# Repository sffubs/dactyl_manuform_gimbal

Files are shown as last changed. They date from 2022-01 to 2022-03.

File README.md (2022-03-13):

# Dactyl-Manuform-Gimbal keyboard
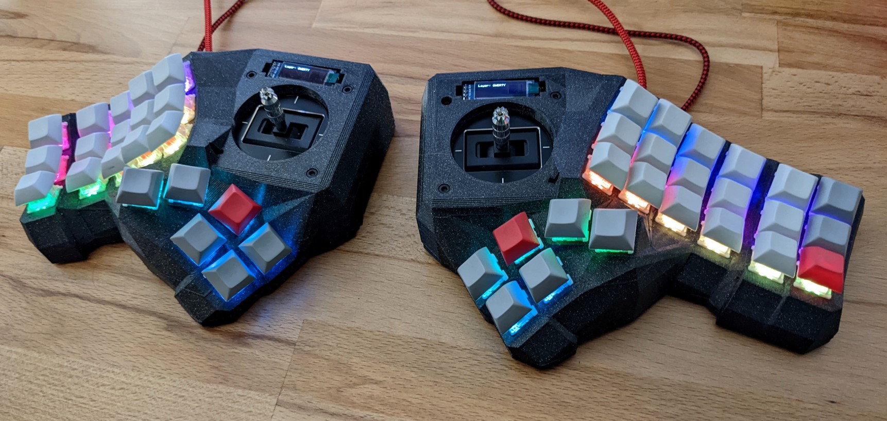
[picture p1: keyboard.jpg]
keyboard


Why? I wanted to build something a bit different, something that I'd not seen before. I wondered what a keyboard would look like if I merged it with an RC controller, and tried using the RC gimbals as a mouse.

The result is quite fun. It's fairly space-efficient, and allows me to use the mouse with either hand. It has proximity sensors to detect when your hand is on the joystick, and turns some of the keys into mouse buttons. Haptic feedback helps to tell when you have switched layers, or long-pressed a key.

You might have noticed it has more keys on the right than the left. This is because I wanted the option to use it with [Plover](http://www.openstenoproject.org/plover/), which for a standard layout requires a minimum of 6 columns on the right, and 5 columns on the left. (I've not actually tested it with Plover, having built a [different keyboard](https://www.thingiverse.com/thing:5021950) for that in the meantime).

Fair warning: there is quite a lot of soldering involved if you want to make one:

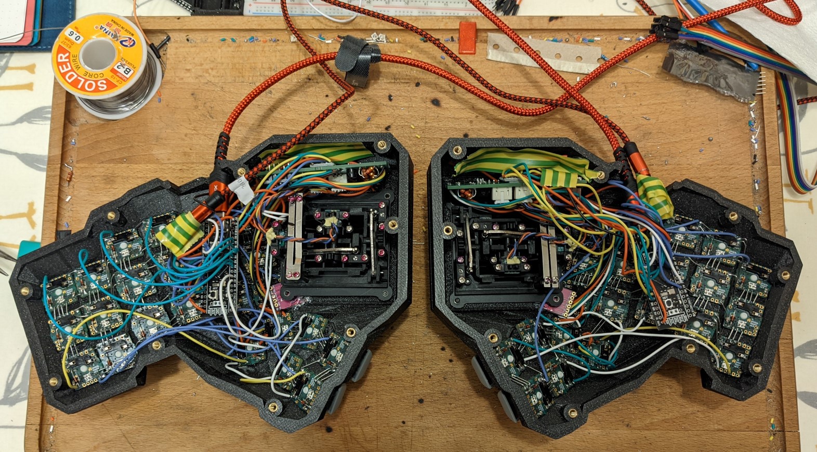
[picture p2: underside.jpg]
underside


## Components
### Keys
I picked gateron red switches and DSA keycaps, sold to me by [Mechboards](mechboards.co.uk).

### Gimbals
The twist in this design is the inclusion of a pair of joysticks. These are RC gimbals - see [here](FrSky_M9.md) for some details of how they are wired up.

### Proximity
The keyboard uses a proximity switch to detect when a hand is over the joystick, and uses this to switch the mouse buttons on. This is using an [APDS-9660](https://www.sparkfun.com/products/12787) sensor & breakout board which is glued to the underside of the case (it's the purple circuit board visible under the corner of the gimbal).

Here it is working:



The proximity sensor looks up through the little square hole next to the gimbal, so your hand needs to be somewhere over that hole for it to activate:

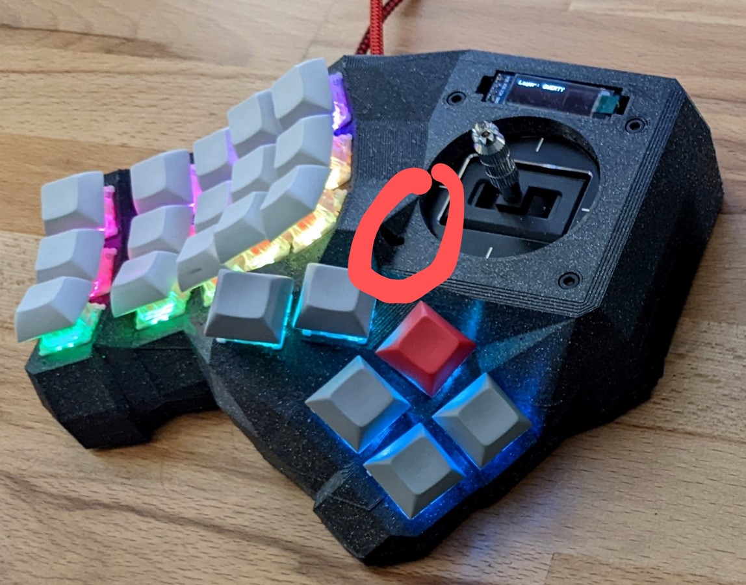
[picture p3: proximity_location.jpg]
proximity location


It will trigger unexpectedly if you get hair over that hole, so I advise you to keep your cat away from it.

### Controller
Originally this was designed to work with two [Pro Micro](https://www.sparkfun.com/products/12640) controllers, but these didn't really have enough flash for the QMK features I wanted.

So I used a beefier board that I was familiar with: the [Teensy 3.2](https://www.hobbytronics.co.uk/teensy-v32), which has been really good to me before. However, it turns out that QMK only sort-of supports the Teensy, so I had a lot of trouble getting it to work reliably.

In the end, I gave up, and swapped to a pair of [STM32F401CCU6 "Black pill"](https://stm32-base.org/boards/STM32F401CCU6-WeAct-Black-Pill-V1.2.html) controllers. These work flawlessly with QMK, though I did manage to kill two boards during assembly, and I'm not quite sure how.

In any case, the swap from the original 5v board to a 3.3v one meant that a level-shifter had to be added between the board and the I2C and LED lines on the breakout board.

Here's how the blackpill controller is wired:

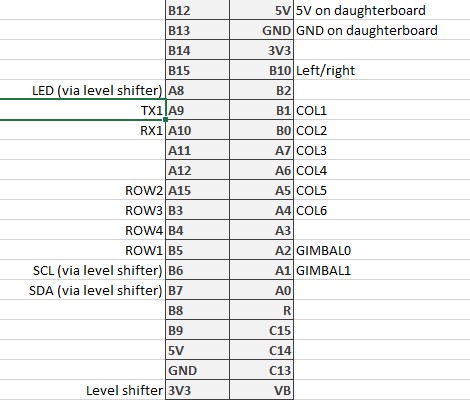
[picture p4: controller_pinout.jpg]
controller_pinout


B10 should be wired to 3V3 on the left-hand half, and to GND on the right-hand half.

Remember that TX1 on the left-hand half needs to be connected to RX1 on the right-hand half, and vice-versa.

### Haptic
I wanted to try getting some haptic feedback from the keyboard, for example when using mod-taps, or when switching to/from mouse mode. QMK has support for the [DRV2605L](https://learn.adafruit.com/adafruit-drv2605-haptic-controller-breakout) driver built in, so I used this.

I picked a linear resonant actuator to use with it, the Jinlong G0832012. Not for any highly specific reason; it was easily available and looked like roughly the right thing.

### LEDs & per-key PCBs
Per-key RGB LEDs are the cornerstone of a fancy mechanical keyboard! I had to have them. To try and keep things tidy, I used [Amoeba Royale](https://github.com/mtl/keyboard-pcbs/tree/master/amoeba-royale) per-key PCBs, printed for me by [Aisler](https://aisler.net). I got a bunch of SK6812 mini 3535 LEDs to to go with them, along with kailh hotswap sockets, and some small signal diodes.

Honestly, they were still quite painful to use. The holes in the PCB had to be filed out before the LEDs would fit in them, and the LED casings would melt if the soldering iron was on them for more than half a second. I had a couple of PCBs that were faulty also.

Here was my method for soldering them:
- Sit the LED in the hole
- Spread some flux over the back of the LED
- For each terminal
	- Put some solder on the PCB pad
	- Dag it onto the LED. Hopefully you will get a little solder bridge form
- Try once for each pad, and if it didn't work, leave it for a couple of minutes to cool before you try again.
- Repeat until all connections are made, then test the PCB.

However, once the whole lot was wired up, they do look quite tidy. The PCBs are not secured to the case, it seems to be enough just to press-fit them onto the back of the keys.

### Split communication
The two halves communicate through a TRRS connector. However, this just provides serial communications and a common ground wire - I left the 5v wire unconnected. Both of the halves need to be connected to the host computer over USB. This is for two reasons:
- Each half can send its own mouse events, which simplifies things
- I think the power draw for the whole keyboard might exceed 500ma - certainly I had some problems trying to power the whole thing from a single USB port

### OLED
I bought a pair of "OLED screens" from Mechboards, because of course I wanted my keyboard to have a screen! Actually this turned out to be a really helpful debugging tool, and I ended up printing a lot of diagnostic information to the OLED screen. I suspect they are SSD1306 128x32 screens, since they worked in QMK without any modifications.

## Daughterboard PCB
There are a lot of connections in this keyboard: the haptic breakout board, proximity board, OLED, LED, gimbals, TRRS connection. Wiring all of these directly to the controller would be difficult.

To simplify things, I designed a PCB to hold all of these connections. It also contains a 3.3v regulator to drive the ADPS9660 board, from back when the whole system was designed to run on 5v.
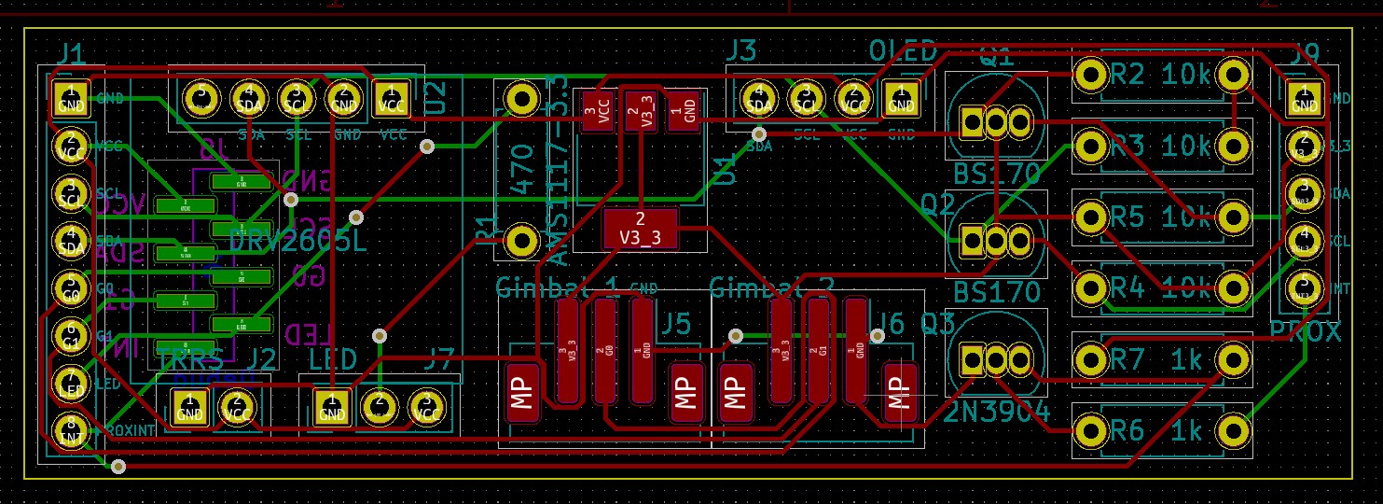
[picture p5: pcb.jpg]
PCB


Originally the SCL, SDA, and LED connections on the left were meant to go straight to pins on the pro micro controller. However, when using this with a blackpil controller, you will need to use a [level shifter](https://learn.sparkfun.com/tutorials/bi-directional-logic-level-converter-hookup-guide/all) to convert between 3.3v and 5v.

Here are the sources:
- [dactyl-manuform-gimbal.kicad_pcb](dactyl-manuform-gimbal.kicad_pcb)
- [dactyl-manuform-gimbal.pro](dactyl-manuform-gimbal.pro)
- [dactyl-manuform-gimbal.sch](dactyl-manuform-gimbal.sch)

I had mine manufactured by [Aisler](https://aisler.net/).

You will also need these parts to make up the board:
- Q3: 2N3904 TO-92
- R6 & R7: 1k resistor
- R2, R3, R4, R5: 10k resistor
- Q1 & Q2: BS170 TO-92
- R1: 470R resistor
- J5 & J6: JST_PH_B3B header
- AMS1117 3.3v voltage regulator
- Adafruit DRV2506L haptic driver

## Geometry
The geometry was generated using a fork of Joshua Shreve's dactyl-keyboard generator:

https://github.com/sffubs/dactyl-keyboard/tree/gimbal

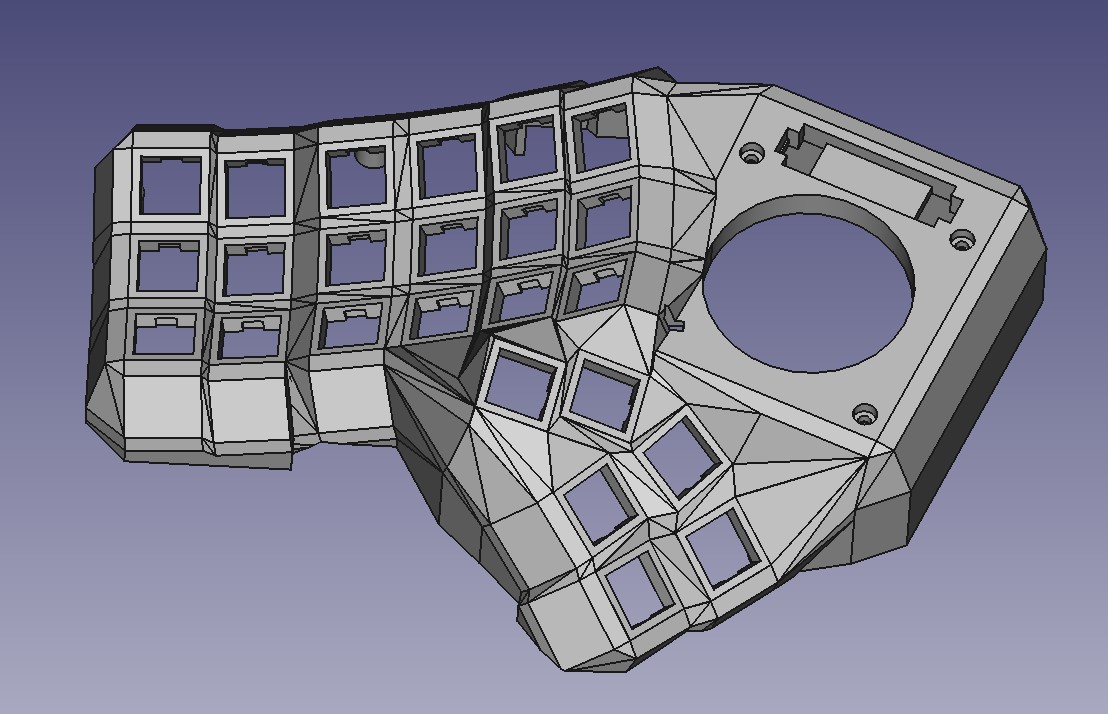
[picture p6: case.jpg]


I custom-designed some controller trays to fit:

https://cad.onshape.com/documents/eb5f1e8bc035539a3b22c66d/w/b0de5830ef436e9c93686258/e/9e4ae3f698d1b142e7089f96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

This for the right-hand keyboard - you will need to print the mirror image for the left-hand keyboard.

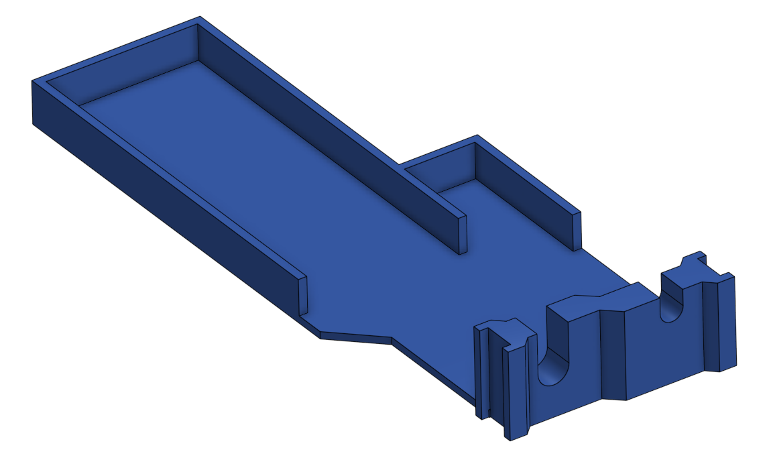
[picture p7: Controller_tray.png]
Controller tray


The final files I used are here:
- [DM_left_final.step](DM_left_final.step)
- [DM_left_final.stl](DM_left_final.stl)
- [DM_left_plate_final.stp](DM_left_plate_final.stp)
- [DM_left_plate_final.stl](DM_left_plate_final.stl)
- [DM_right_final.step](DM_right_final.step)
- [DM_right_final.stl](DM_right_final.stl])
- [DM_right_plate_final.step](DM_right_plate_final.step)
- [DM_right_plate_final.stl](DM_right_plate_final.stl)
- [Controller_tray.stl](Controller_tray.stl)
- [DM_OLED_clip.stl](DM_OLED_clip.stl)

## Printing
I printed this on my Ender 3, using Prusament Galaxy Black PLA filament, with a 0.4mm nozzle at 0.2mm resolution. I used tree-style supports, which much reduced the time and plastic required.

## Firmware

The keyboard runs on QMK, and the firmware can be found here:

https://github.com/sffubs/qmk_firmware/tree/master/keyboards/handwired/dactyl_manuform_gimbal

Build using 

`qmk -kb handwired/dactyl_manuform_gimbal -km default`

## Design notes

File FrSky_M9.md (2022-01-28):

# Frsky M9 gimbal

## Wiring

These are 3.3v hall-effect joysticks. They have two sensors which are wired as:
- Red: 3.3v
- Black: 0v
- Yellow or blue: signal (between 0v and 3.3v)

These signals can be easily read using an ADC, and used to make a USB joystick or mouse.

Here's the joystick as it arrives:

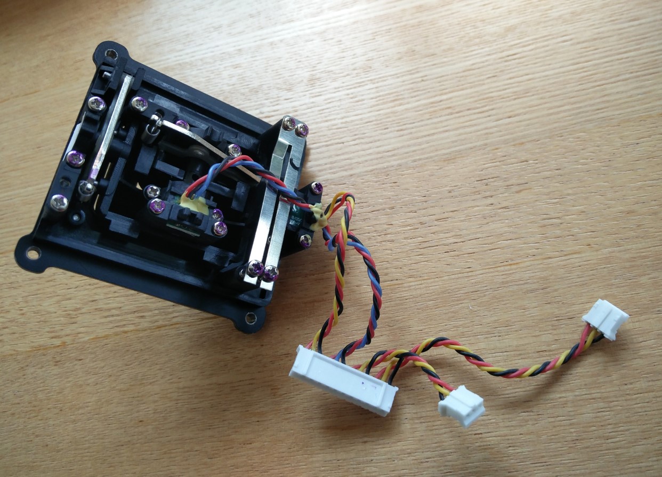
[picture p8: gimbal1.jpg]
gimbal1


The wires are all connected to this large JST connector, for installation into a Taranis RC controller:

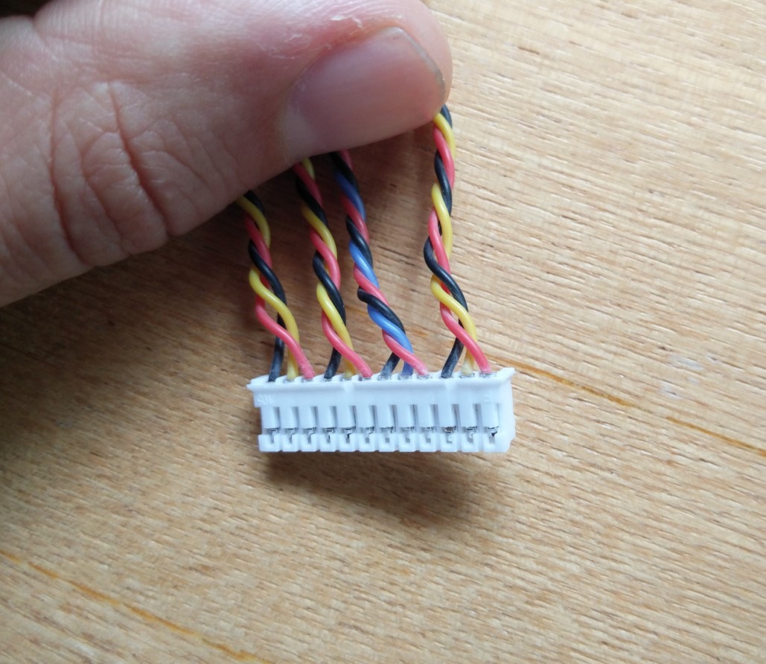
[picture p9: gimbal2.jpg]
gimbal2

Using a craft knife, you can lift the plastic tabs of the JST connectors, and pull the pins out. Then you can just plug the critical wires back into the 3-pin JST connectors:

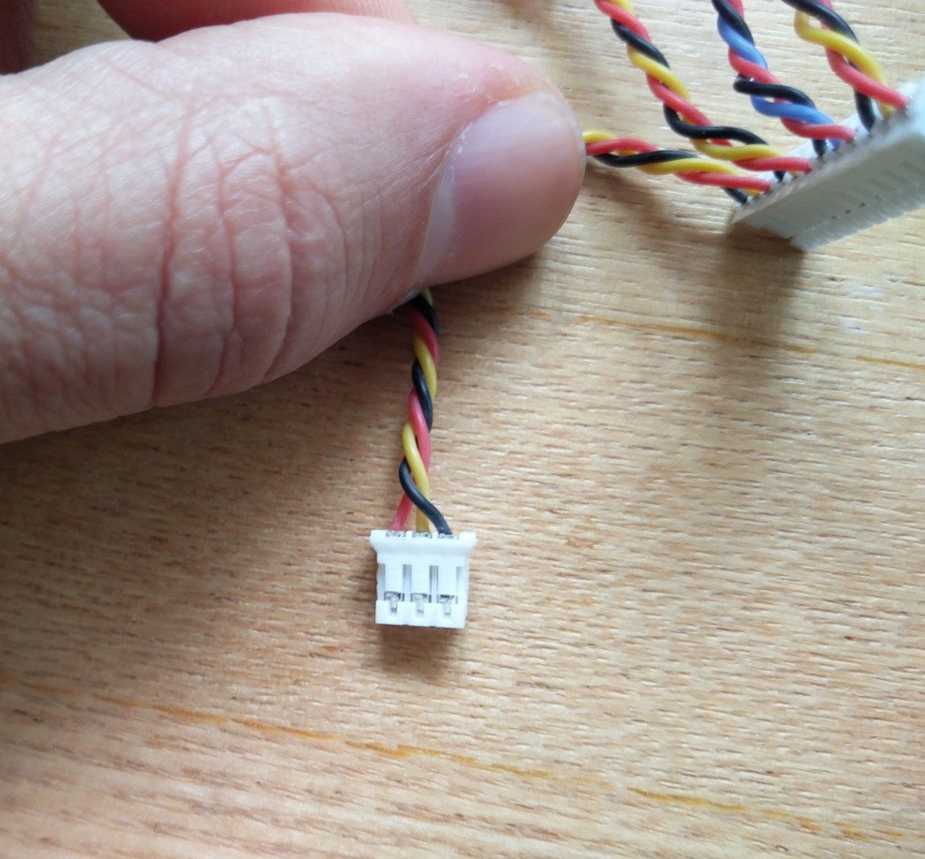
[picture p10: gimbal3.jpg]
gimbal3

The end result is much more suitable for integrating into a different project:

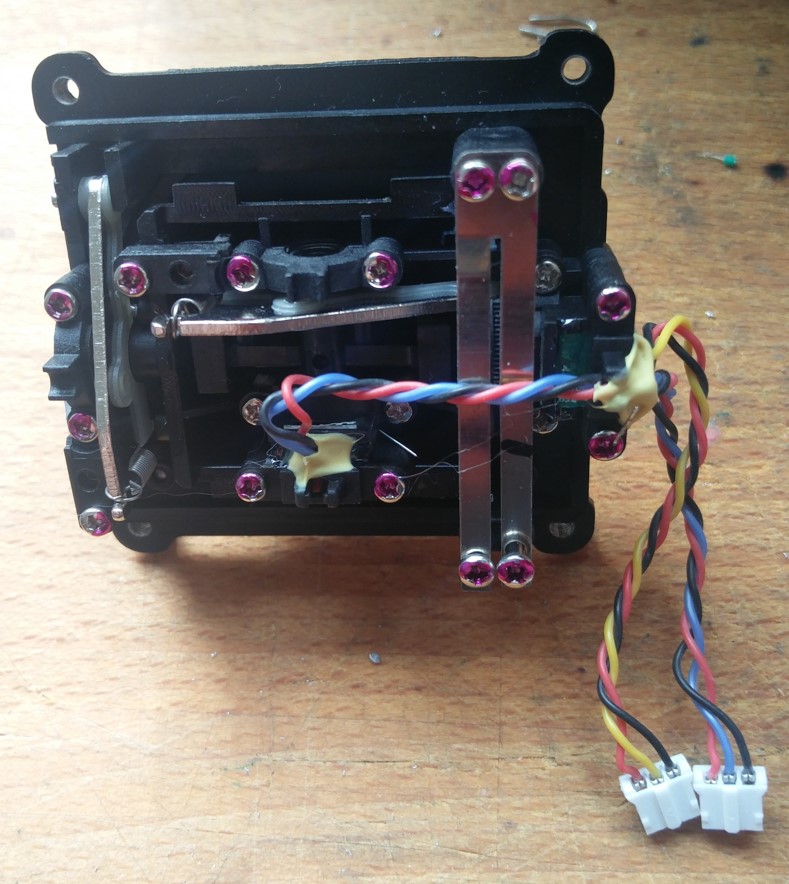
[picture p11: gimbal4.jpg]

These are JST-PH 2.0 connectors.

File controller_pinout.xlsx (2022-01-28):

 | B12 | 5V | 5V on daughterboard
 | B13 | GND | GND on daughterboard
 | B14 | 3V3
 | B15 | B10 | Left/right
LED (via level shifter) | A8 | B2
TX1 | A9 | B1 | COL1
RX1 | A10 | B0 | COL2
 | A11 | A7 | COL3
 | A12 | A6 | COL4
ROW2 | A15 | A5 | COL5
ROW3 | B3 | A4 | COL6
ROW4 | B4 | A3
ROW1 | B5 | A2 | GIMBAL0
SCL (via level shifter) | B6 | A1 | GIMBAL1
SDA (via level shifter) | B7 | A0
 | B8 | R
 | B9 | C15
 | 5V | C14
 | GND | C13
Level shifter | 3V3 | VB

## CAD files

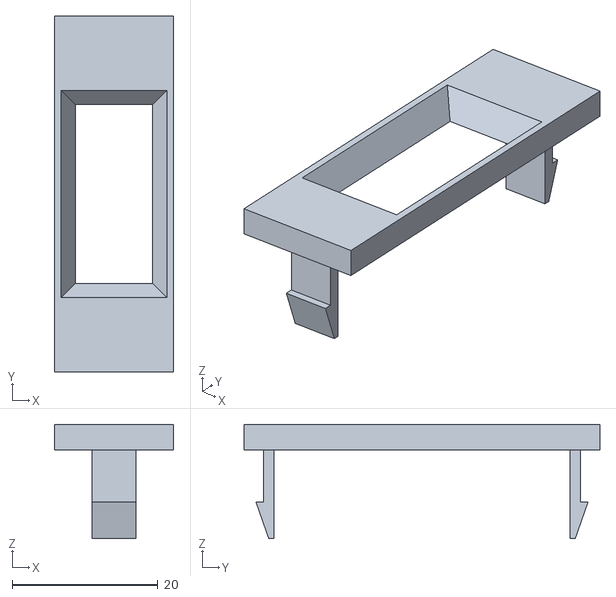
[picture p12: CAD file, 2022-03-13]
DM_OLED_clip.stl
16.4 x 48.9 x 15.7

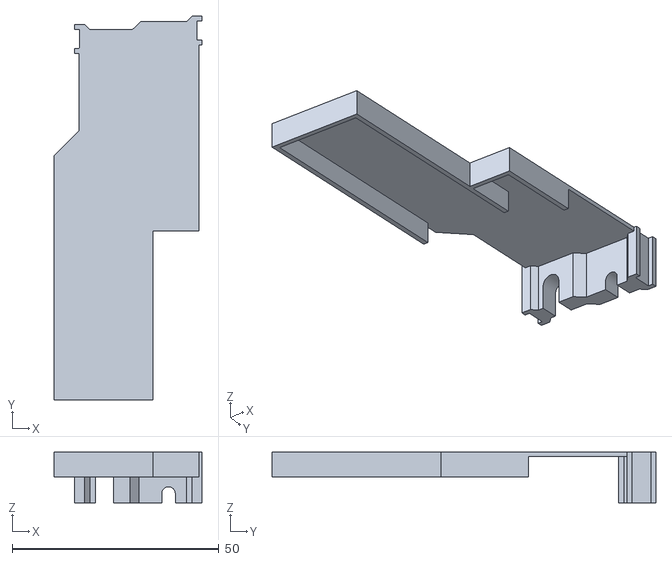
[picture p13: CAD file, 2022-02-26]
Controller_tray.stl
35.8 x 92.7 x 12.2

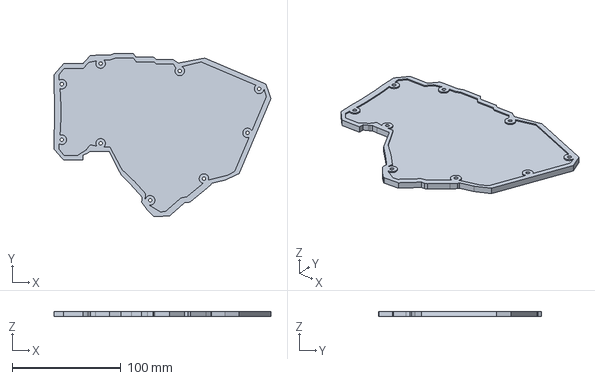
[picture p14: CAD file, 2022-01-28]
DM_left_plate_final.stp
200.0 x 150.4 x 5.00 mm

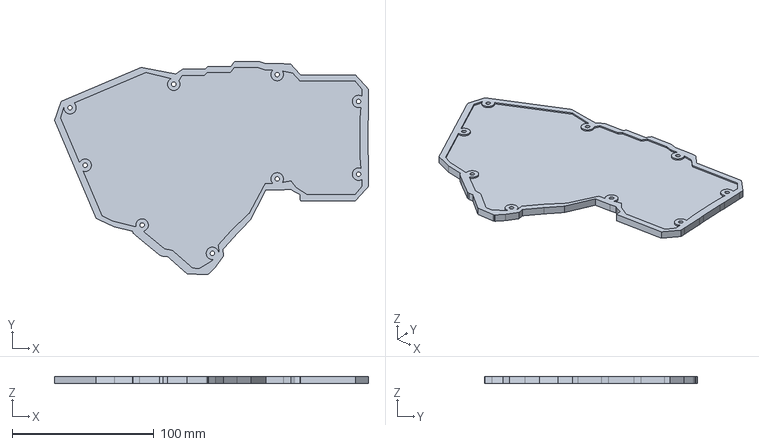
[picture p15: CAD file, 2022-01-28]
DM_right_plate_final.step
221.3 x 150.4 x 5.00 mm

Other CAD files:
DM_left_plate_final.stl
DM_right_plate_final.stl

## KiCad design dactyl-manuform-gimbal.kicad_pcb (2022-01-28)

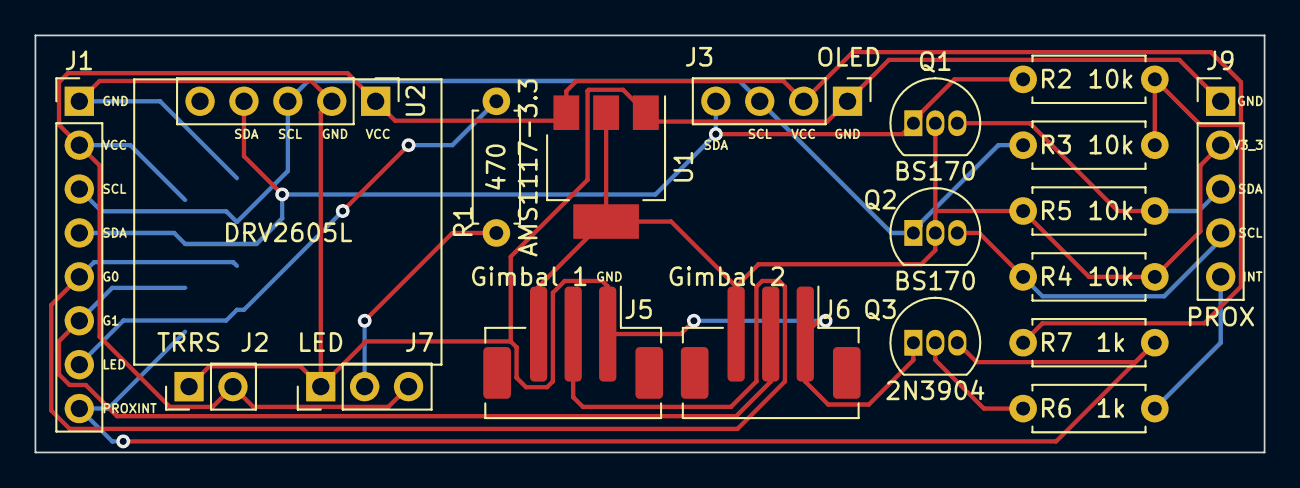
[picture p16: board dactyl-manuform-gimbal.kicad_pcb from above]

Board: 2 copper layers, 71.1 x 24.1 mm, 20 parts (1 on the bottom side), 14 nets.

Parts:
J1: Arduino; PinHeader_1x08_P2.54mm_Vertical
J2: TRRS; PinHeader_1x02_P2.54mm_Vertical
J3: OLED; PinHeader_1x04_P2.54mm_Vertical
J5: Gimbal 1; JST_PH_B3B-PH-SM4-TB_1x03-1MP_P2.00mm_Vertical
J6: Gimbal 2; JST_PH_B3B-PH-SM4-TB_1x03-1MP_P2.00mm_Vertical
J7: LED; PinHeader_1x03_P2.54mm_Vertical
J8: Debug; PinHeader_1x08_P1.27mm_Vertical_SMD_Pin1Left
J9: PROX; PinHeader_1x05_P2.54mm_Vertical
Q1, Q2: BS170; TO-92_Inline
Q3: 2N3904; TO-92_Inline
R1: 470; R_Axial_DIN0207_L6.3mm_D2.5mm_P7.62mm_Horizontal
R2, R3, R4, R5: 10k; R_Axial_DIN0207_L6.3mm_D2.5mm_P7.62mm_Horizontal
R6, R7: 1k; R_Axial_DIN0207_L6.3mm_D2.5mm_P7.62mm_Horizontal
U1: AMS1117-3.3; SOT-223-3_TabPin2
U2: DRV2605L; DRV2605L_Adafruit

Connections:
/G0: J1.5, J5.2, J8.5
/G1: J1.6, J6.2, J8.6
/GND: J1.1, J2.1, J3.1, J5.1, J6.1, J7.1, J8.1, J9.1, Q3.1, U1.1, U2.2
/INT: J1.8, J8.8, Q3.3, R7.2
/INT3_3: J9.5, R6.2
/LED: J1.7, J8.7, R1.1
/SCL: J1.3, J3.3, J8.3, Q2.1, R3.1, U2.3
/SCL3_3: J9.4, Q2.3, R5.1
/SDA: J1.4, J3.4, J8.4, Q1.1, R2.1, U2.4
/SDA3_3: J9.3, Q1.3, R4.1
/V3_3: J5.3, J6.3, J9.2, Q1.2, Q2.2, R4.2, R5.2, U1.2
/VCC: J1.2, J2.2, J3.2, J7.3, J8.2, R2.2, R3.2, R7.1, U1.3, U2.1
unnamed: J7.2, R1.2
unnamed: Q3.2, R6.1

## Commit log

2022-01-28 Initial commit of details about how I built this keyboard.
    [DM_left_plate_final.stl, DM_left_plate_final.stp, DM_right_plate_final.step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]
2022-01-28 Switched to standard Markdown syntax.
2022-01-28 Added details of per-key PCBs.
2022-01-28 Added method for soldering LEDs.
2022-01-28 Added gif showing the proximity sensor working.
    [controller_pinout.xlsx]
2022-01-28 Added picture showing proximity sensor location.
2022-02-26 Added controller tray.
    [Controller_tray.stl]
2022-03-13 Added OLED clip geometry.
    [DM_OLED_clip.stl]
